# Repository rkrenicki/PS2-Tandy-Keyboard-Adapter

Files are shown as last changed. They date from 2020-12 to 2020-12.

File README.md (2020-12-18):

# PS2 to Tandy 1000 Keyboard Adapter

This is a simple in-line adapter to allow use of more modern PS2 Keyboards on early Tandy 1000 computers.   This adapter works on 1000, 1000A, 1000HD, 1000SX, and 1000TX computers.

## Prerequisites

This adapter is for the Tandy 1000, 1000A, 1000HD, 1000SX, and 1000TX computers only.  It will not work for any other computer model as it is

## Installing

This adapter simply connects in-line between your PS2 keyboard and the Tandy 1000 computer.  Simple plug-and-play.

## Bill of Materials
|Quan |Ref(s) |Mouser Part Number  |Description 
|-----|---|---|---
| 1 |U1 |556-ATTINY85-20PU |ATTiny85-20PU Micrcontroller
| 2 |R1, R2 |603-CFR-12JB-52-4K7 |4.7k ohm Resistor
| 1 |R3 |603-CFR-12JB-52-150R|150 ohm Resistor
| 1 |F1 |576-0251001.MRT1L |1A Polyfuse
| 1 |C1 |594-A101J15C0GF5TAA |100pF Multi Layer Ceramic Capacitor
| 1 |C2 |594-A104M15X7RF5TAA |0.1uF Multi Layer Ceramic Capacitor
| 1 |J1 |806-KMDGX-6S-BS |MiniDIN 6 Socket

## BIOS

The ATTiny software is written by Scott Baker.

## Built With

* [KiCAD EDA](http://www.kicad-pcb.org/)

## Authors

* **Rob Krenicki** - [rkrenicki](https://github.com/rkrenicki)

## License

Creative Commons Attribution-ShareAlike 4.0 International License (http://creativecommons.org/licenses/by-sa/4.0/)

## Attribution

This board was derrived from works by, uses design elements from, or contains sofware writen by the following:
* Scott Baker (https://www.smbaker.com/tandy-1000-upgrades-ps2-tandy-keyboard-adapter)
* PS/2 Keyboard Library (http://www.nerdkits.com/videos/interrupts_and_ps2_keyboard/)

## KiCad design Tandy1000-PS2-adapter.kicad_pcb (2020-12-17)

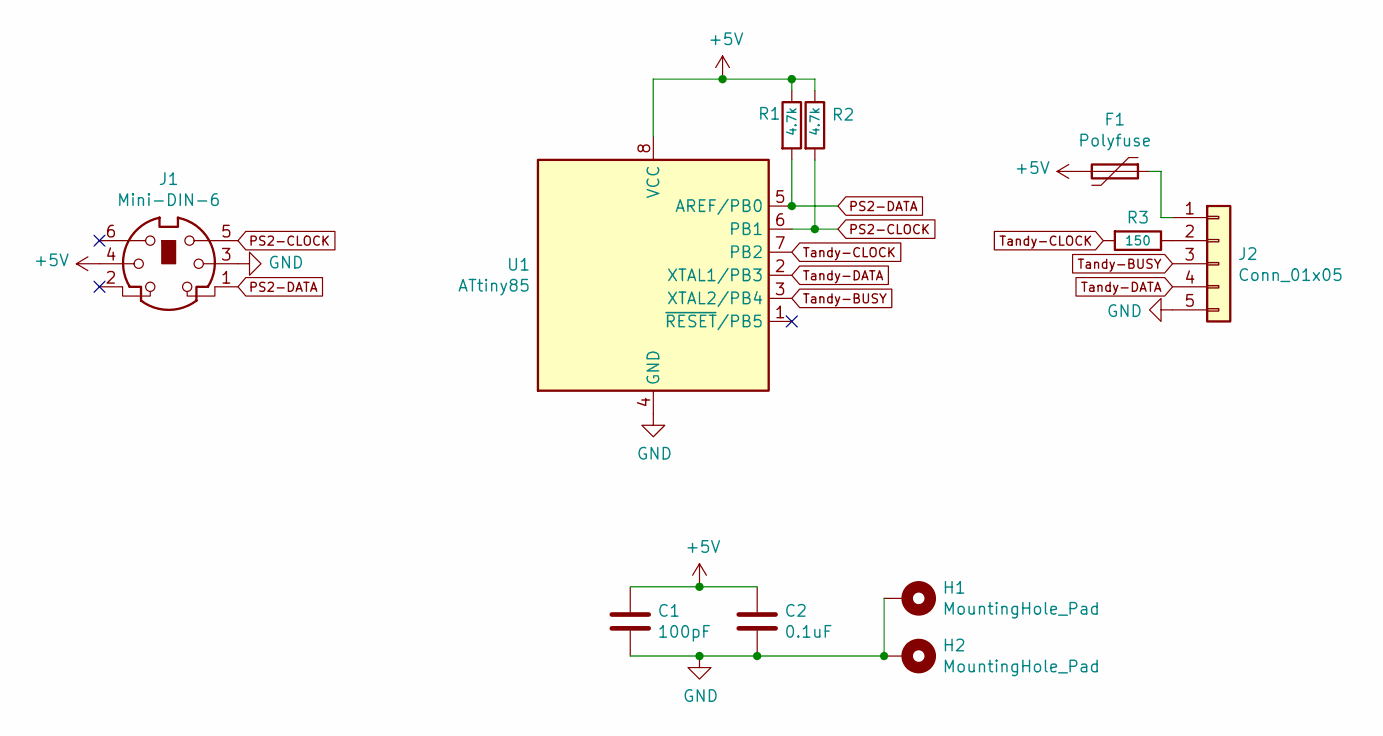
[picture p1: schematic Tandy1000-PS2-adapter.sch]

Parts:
C1: 100pF; R_Axial_DIN0204_L3.6mm_D1.6mm_P5.08mm_Horizontal
C2: 0.1uF; R_Axial_DIN0204_L3.6mm_D1.6mm_P5.08mm_Horizontal
F1: Polyfuse; R_Axial_DIN0207_L6.3mm_D2.5mm_P10.16mm_Horizontal
H1, H2: MountingHole_Pad; MountingHole_2.7mm_M2.5_DIN965_Pad
J1: Mini-DIN-6; MINI-DIN-6-FULL-SHIELD
J2: Conn_01x05; PinHeader_1x05_P2.54mm_Vertical
R1, R2: 4.7k; R_Axial_DIN0204_L3.6mm_D1.6mm_P5.08mm_Horizontal
R3: 150; R_Axial_DIN0204_L3.6mm_D1.6mm_P5.08mm_Horizontal
U1: ATtiny85; DIP-8_W7.62mm

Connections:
+5V: C1.1, C2.1, F1.2, J1.4, R1.1, R2.1, U1.8 (VCC)
GND: C1.2, C2.2, H1.1, H2.1, J1.3, J2.5, U1.4 (GND)
unnamed: F1.1, J2.1
unnamed: J2.2, R3.1
PS2-CLOCK: J1.5, R2.2, U1.6 (PB1)
PS2-DATA: J1.1, R1.2, U1.5 (AREF/PB0)
Tandy-BUSY: J2.3, U1.3 (XTAL2/PB4)
Tandy-CLOCK: R3.2, U1.7 (PB2)
Tandy-DATA: J2.4, U1.2 (XTAL1/PB3)

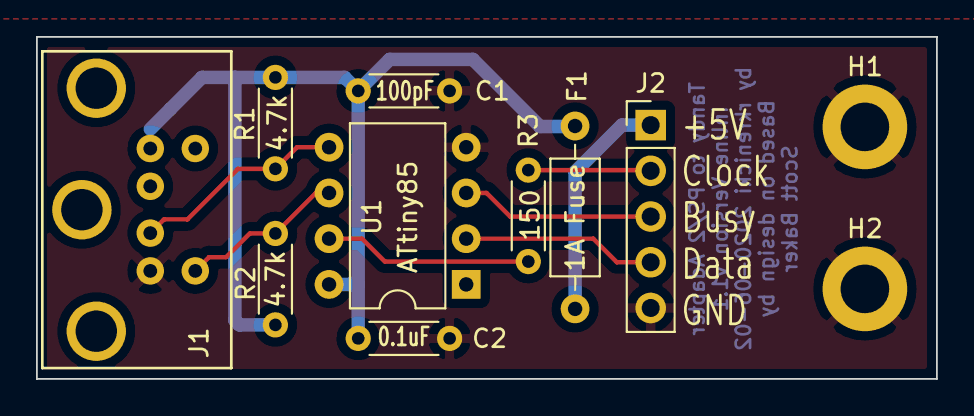
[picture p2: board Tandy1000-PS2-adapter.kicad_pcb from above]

Board: 2 copper layers, 50.0 x 19.0 mm, 11 parts (0 on the bottom side), 9 nets.
